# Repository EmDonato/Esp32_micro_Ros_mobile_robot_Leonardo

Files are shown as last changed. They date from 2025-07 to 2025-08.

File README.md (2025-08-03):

# Leonardo ESP32 Differential-Drive Unicycle Robot with micro-ROS and ROS 2 Humble

A mobile differential-drive unicycle robot powered by an **ESP32** microcontroller and seamlessly integrated with **ROS 2 Humble** and **micro-ROS** over Wi‑Fi. It fuses wheel encoder data and IMU measurements for accurate odometry, publishes LiDAR scans for SLAM, and subscribes to gamepad commands for teleoperation.

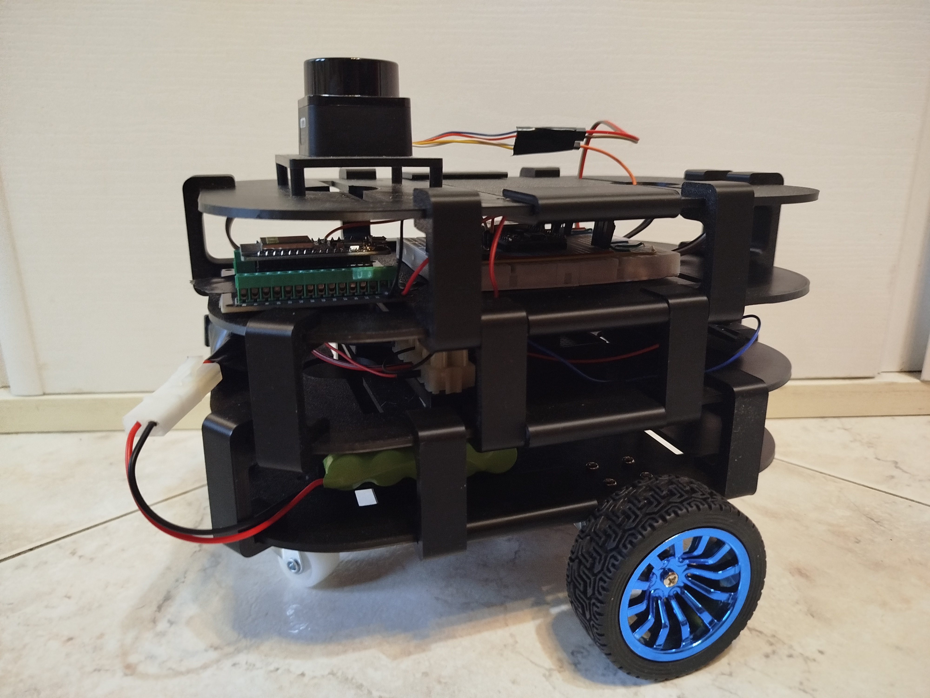
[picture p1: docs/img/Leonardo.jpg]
Leonardo Robot


> **Demo Video:** `docs/video/demo.mp4`

## 🗂️ Directory Layout

```text
/
├── leonardo/                 # Companion PC ROS 2 workspace
├── Leonardo_esp32/           # Primary ESP32 firmware
├── Leonardo_Lidar/           # Secondary ESP32 LiDAR node
├── libraries_arduinoIDE/     # Custom Arduino libraries
├── chassis_leonardo_3Dprint/ # 3D chassis CAD & STLs
├── docs/
│   ├── img/                  # Project images
│   └── video/                # Demo videos
└── README.md                 # This overview file
```

---

## 📦 Dependencies

Before getting started, make sure you have the following installed on your companion PC:

* **ROS 2 Humble Hawksbill**
* **micro-ROS Agent**

  ```bash
  sudo apt update
  sudo apt install ros-humble-micro-ros-agent
  ```
* **ROS Toolbox (slam\_toolbox)**

  ```bash
  sudo apt install ros-humble-slam-toolbox
  ```
* **Nav2 (Navigation2 stack)**

  ```bash
  sudo apt install ros-humble-nav2-bringup
  ```
* **RViz 2**

  ```bash
  sudo apt install ros-humble-rviz2
  ```

Additional system dependencies:

* Python 3.10+ packages: `colcon-common-extensions`, `rosdep`
* Arduino IDE (for firmware builds)

---

## 🔧 Hardware Setup

* **Microcontroller:** ESP32 DevKit (Wi‑Fi enabled)
* **Wheel Encoders:** Magnetic encoders on 12 V DC motors (25GA‑370, 130 RPM)
* **IMU:** MPU6050 via I2C (SDA/SCL)
* **Motor Driver:** L298N (PWM + digital direction pins)
  [motorDriver library](https://github.com/EmDonato/motorDriver.git)
* **LiDAR:** LD06 on secondary ESP32
  [LD06 module](https://github.com/EmDonato/ld06_esp32_microRos.git)
* **Battery:** 12 V NiMH pack
* **DC-DC Converter:** XL4015 step‑down module

---

## 🚀 Core Components

### Companion PC (`leonardo`)

* Teleoperation: `joy_node` & `teleop_twist_joy` for gamepad control
* Command Arbitration: `twist_mux` merging multiple `/cmd_vel` sources
* TF Broadcasters: `odom → base_link`, `base_link → base_laser`
* Time Synchronization: `/time_sync` messages align PC and ESP32 clocks
* SLAM Mapping: `slam_toolbox` for real-time 2D mapping
* Navigation: Nav2 bringup for path planning and recovery behaviors
* Visualization: preconfigured RViz2 layout

### ESP32 Firmware Modules

#### Main ESP32 (`Leonardo_esp32`)

* Odometry: complementary filter fusing encoder + IMU data
* Control: feedforward + PID loops generating motor commands
* micro-ROS: publishes `/odom`, subscribes `/cmd_vel_mux`, etc.

#### LiDAR Node (`Leonardo_Lidar`)

* Packet Parsing: decodes LD06 scan data into distances & confidences
* Scan Assembly: builds full 360° `LaserScan` messages
* Timestamp Sync: applies PC-derived offset for accurate stamps
* ROS 2 Interface: publishes scans and debug logs

### Libraries (`libraries_arduinoIDE`)

* Motor driver abstractions
* PID controller utilities (with feedforward and deadzone)

### Chassis Model (`chassis_leonardo_3Dprint`)

* CAD files and STL exports for 3D-printing the robot chassis

---

## 📋 Recent Updates

* **Unified Workspace:** merged PC and ESP32 projects into one directory structure
* **Time Sync:** added periodic `/time_sync` publisher and subscriber nodes
* **Twist\_mux:** configured priority and timeouts for manual vs. autonomous commands
* **IMU msg:** send imu msg
* **LiDAR Node:** enhanced error handling and synchronized scans every 30 s
* **Libraries:** released motor driver feedforward update and advanced PID tuning
* **Nav2 confi file** added config file for nav2 DWB control and PP control (not recommended)
---

## 🚀 Next Steps

* Integrate autonomous exploration

---

## ⚙️ Usage Examples

### 1️⃣ Source Workspace & Launch Leonardo

```bash
# Build and source your workspace:
colcon build --symlink-install
source install/setup.bash

# Launch the main robot bringup:
ros2 launch leonardo launch_leonardo.py
```

### 2️⃣ SLAM (slam\_toolbox)

```bash
ros2 launch slam_toolbox online_async_launch.py \
  slam_params_file:=/your/Full/path/Leonardo/src/mio_slam_toolbox/config/mapper_params_online_async.yaml
```

### 3️⃣ Navigation (Nav2)

```bash
ros2 launch nav2_bringup navigation_launch.py \
  params_file:=/your/Full/path/Leonardo/config/config_param_nav2DWB.yaml
```

---

## 📄 License

Released under the **MIT License**. See [LICENSE](LICENSE) for details.

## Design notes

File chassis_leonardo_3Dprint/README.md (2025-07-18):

# Chassis Components Directory

This directory contains all the 3D model files (`.stl` and `.f3d`) for the chassis components of the mobile robot platform. Use these files to assemble, simulate, or 3D-print the structural parts of the robot.

---

## Folder Structure

* **Screw\&Nut\_1/**

  * Contains M4 screws and nuts (package 1) used for fastening modular plates and support brackets.

* **Screw\&Nut\_2/**

  * Contains an additional set of M4 screws and nuts (package 2) for supplemental assembly needs.

* **basechassisLeonardo/**

  * Modular platform plates. Two of these plates combine to form the complete chassis base. Each plate shares the same hole pattern for M4 fasteners, ensuring interchangeable assembly.

* **reggiL298N/**

  * Support bracket designed to mount the L298N motor driver securely to the chassis.

* **wire\_linear\_bus/**

  * Cable guide structure for routing wiring along the linear bus of the chassis.

* **holder\_DCDC/**

  * Mounting bracket for the DC–DC converter module. Ensures stable positioning and clearance.

* **battery/**

  * Battery compartment housing. Designed to fit the standard Li‑ion battery pack, with snap‑fit features for quick insertion/removal.

* **jointer/**

  * Snap‑fit connector piece that links two modular base plates. Enables quick assembly without additional hardware.

* **jointer\_level/**

  * Strap‑like clamps that secure stacked base modules at different levels, allowing multi‑tiered chassis configurations.

---

## Usage Notes

* All assemblies use M4 hardware; verify screw lengths to avoid interference.
* `.f3d` files are native Fusion 360 designs—open them to inspect sketches, constraints, and assemblies.
* `.stl` exports are ready for slicing and 3D printing; check tolerances if fitting snap‑fits.
* Maintain consistent hole alignment when stacking modules with `jointer_level` clamps.

For questions or contributions, please open an issue in the repository.

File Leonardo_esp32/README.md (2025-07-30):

# Main ESP32 code
In this directory there is the core code for the project, the one to up load to the main esp32 of the robot.
It's organized in one .ino file and some .h and .cpp file so it's developed for arduinoIDE.
The purpose of the script is to build up all the microRos arquitecture for comunication and control.

## Software Architecture

### Leonardo.ino

* **setup()**: Initializes Serial, motor driver, IMU (with calibration), encoders (attach ISRs), PID controllers, and micro-ROS.
* **loop()**: Spins the micro-ROS executor to handle timers and subscriptions.

### Variable.hpp / Variable.cpp

* **Global Constants**: Hardware pin definitions, encoder PPR, wheel geometry, PID limits, etc.
* **Extern Objects**: `motorDriver`, `encoder_L`, `encoder_R`, `imu`, `odom_msg`, `executor`, etc.

### ISR.hpp / ISR\_Handlers

* **encoderISR\_L / encoderISR\_R**: Interrupt service routines for left/right encoders, updating tick counts and direction.

### EncoderPoseEstimator

* **Purpose**: Convert wheel RPM to linear and angular velocity and integrate heading.
* **Key Method**: `update(rpm_left, rpm_right, dt)` computes velocities and updates `theta_enc`.

### UnicycleOdometry

* **Purpose**: Integrate fused linear and angular velocities to track `(x, y, theta)` pose.
* **Key Method**: `updateFromFusion(v, omega, theta, dt)` updates position based on current heading.

### ControlTools

* **computeRPM**: Convert angular velocity (rad/s) to RPM.
* **normalize\_angle**: Wrap angles to `[-π, π]`.
* **complementaryFilter**: Fuse encoder and IMU yaw estimates.

### IMU\_Tools

* **calibrateGyroZ()**: Compute gyroscope Z-axis bias by sampling while stationary.

### micro\_ROS\_fun.hpp / micro\_ROS\_fun.cpp

* **initMicroROS()**: Configures Wi-Fi transport, ROS nodes, publishers, subscribers, timers, and executor.
* **Error Macros**: `RCCHECK`, `RCSOFTCHECK` for robust ROS calls.
* **Callbacks**:

  * `subscription_callback_control`: Updates wheel velocity references on command.
  * `timer_callback_IMU`: Integrates gyro data to update IMU yaw and send it in a dedicated topic.
  * `timer_callback_odometry`: Reads encoders, fuses yaw, updates odometry, and publishes.
  * `timer_callback_ctrl_PID`: Runs PID loops to drive motors.
  * `init_odom_msg`: Initializes odometry message fields.
  * `yaw_to_quat`: Utility to convert yaw to quaternion.
  * `get_now`: Retrieves current time for ROS stamps.
  * `get_n`: Retrieves current time for ROS stamps.

## Workflow

1. **Startup**: ESP32 boots, runs `setup()`, initializes all hardware and micro-ROS.
2. **Calibration**: Gyro bias is calculated by `calibrateGyroZ()`.
3. **Periodic Tasks**:
   * **IMU Timer**: Updates IMU-based yaw every 10 ms an sed it.
   * **Odometry Timer**: Every 50 ms, encoder RPMs are read, heading fused, and odometry published.
   * **Control Timer**: Every 50 ms, PID computes motor commands based on velocity references.
4. **Control**: Velocity commands published to `/velocity_ctrl` topic are received and processed.
5. **Execution**: `loop()` continuously spins the ROS executor to service callbacks.
## micro-ROS Agent & Arduino Library Setup

To enable communication between your ESP32 robot and the ROS 2 network, follow these steps (refer to the official guide: [https://github.com/micro-ROS/micro\_ros\_arduino](https://github.com/micro-ROS/micro_ros_arduino)):

1. **Install and Run the micro-ROS Agent**

   * Ensure ROS 2 Humble is installed on your host (PC or Raspberry Pi).
   * Build and run the agent for UDP transport:

     ```bash
     ros2 run micro_ros_agent micro_ros_agent udp4 --port 8888
     ```

2. **Configure the Arduino micro-ROS Library**

   * Update your workspace’s `colcon.meta` to increase RMW limits:

     ```json
     {
       "rmw_microxrcedds": {
         "cmake-args": [
           "-DRMW_UXRCE_MAX_NODES=5",
           "-DRMW_UXRCE_MAX_PUBLISHERS=10",
           "-DRMW_UXRCE_MAX_SUBSCRIPTIONS=5",
           "-DRMW_UXRCE_MAX_SERVICES=1",
           "-DRMW_UXRCE_MAX_CLIENTS=1",
           "-DRMW_UXRCE_MAX_HISTORY=4",
           "-DRMW_UXRCE_TRANSPORT=custom"
         ]
       }
     }
     ```
   * Rebuild the `rmw_microxrcedds` package:

     ```bash
     colcon build --merge-install --packages-select rmw_microxrcedds
     ```

3. **Verify Connectivity**

   * Be sure to change the wifi parameters with your own parameters (micro_ros_fun.cpp)

This configuration lets your ESP32 publish odometry and subscribe to velocity commands over ROS 2 using micro-ROS.

## Detailed ROS 2 Integration

### Message Types

* **nav\_msgs/Odometry**: publishes robot pose (position + orientation) and velocity.
* **geometry\_msgs/Vector3**: subscribes to control input (left and right wheel angular velocities).

### Published Topics

* **/odom** (`nav_msgs/Odometry`)

  * **Description**: Robot's pose and velocity relative to the `odom` frame.
  * **Message Fields**:

    * `header.stamp`: Timestamp of measurement (built from `millis()`).
    * `header.frame_id`: "odom".
    * `child_frame_id`: "base\_link".
    * `pose.pose.position`: X, Y coordinates.
    * `pose.pose.orientation`: Quaternion from fused yaw.
    * `twist.twist.linear.x`: Linear velocity.
    * `twist.twist.angular.z`: Angular velocity.

* **/debug_log** (`std_msgs/msg/string`)

* **Description**: Log message to advise about the currents status of the microRos inizialization.
  
* **/imu/data** (`sensor_msgs/msg/imu`)

  * **Description**: Robot's IMU data .
 **Message Fields**:

- `header` (`std_msgs/Header`)
  - `stamp` (`builtin_interfaces/Time`): Timestamp of the measurement
  - `frame_id` (`string`): Reference frame (e.g., `"base_link"` or `"imu_link"`)

- `orientation` (`geometry_msgs/Quaternion`)
  - `x`, `y`, `z`, `w`: Orientation as quaternion

- `orientation_covariance` (`float64[9]`): Row-major 3×3 covariance matrix of orientation

- `angular_velocity` (`geometry_msgs/Vector3`)
  - `x`, `y`, `z`: Angular velocity in rad/s

- `angular_velocity_covariance` (`float64[9]`): Row-major 3×3 covariance matrix of angular velocity

- `linear_acceleration` (`geometry_msgs/Vector3`)
  - `x`, `y`, `z`: Linear acceleration in m/s²

- `linear_acceleration_covariance` (`float64[9]`): Row-major 3×3 covariance matrix of linear acceleration
### Subscribed Topics

* **cmd_vel_mux** (`geometry_msgs/msg/twist`)

  * **Description**: Target angular velocities for left (x) and right (y) wheels.
  * **Usage**: Received values are stored in `w_L_ref` and `w_R_ref`, converted to RPM, and fed into PID controllers.

## PID Control library
findable here: https://github.com/EmDonato/PID_control.git or in the libraries_arduinoIDE (recommended)
* **Controllers**: Two independent PID loops for left and right wheels
* **Feedforward**: Enabled to improve dynamic response
* **Deadzone**: Zero threshold prevents jitter around zero velocity

## Calibration

* **Gyroscope**: `calibrateGyroZ()` averages 500 samples to compute bias

---
---

> Once these steps are complete, the robot will be able to receive correct velocity commands, navigate autonomously, and provide real-time diagnostic data for easier debugging and system validation.

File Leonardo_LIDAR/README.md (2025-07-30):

# LD06 LiDAR + ESP32 (Secondary Node) + micro-ROS Humble

This project enables the integration of the LD06 LiDAR sensor with an **ESP32** microcontroller as a **dedicated LiDAR node**, using the **micro-ROS Humble** stack to publish `sensor_msgs/msg/LaserScan` over ROS 2.

---

## 🛠️ Hardware Components

* **ESP32** 
* **LD06 LiDAR** (UART interface, 230400 baud)
* **micro-ROS Agent** running on a host computer or Raspberry Pi

---

## 📦 Software Components

* **Arduino framework for ESP32**
* **micro-ROS Arduino client** for ROS 2 Humble

---
## 🚀 Main Node Overview (`Leonardo_LIDAR.ino`)

This sketch implements:

1. **Wi-Fi transport** for micro-ROS over Ethernet/Wi-Fi.
2. **Publishers**:

   * `/scan` (`sensor_msgs/msg/LaserScan`): LiDAR data
   * `/lidar/debug_log` (`std_msgs/msg/String`): debug messages
3. **Subscriber**:

   * `/time_sync` (`builtin_interfaces/msg/Time`): external timestamp for time synchronization
4. **Executor** to handle time sync callback.
5. **Scan buffer management** and **synchronized publishing**.

### Key Functions

#### `resetLidarScanBuffer()`

Clears `ranges[]`, `intensities[]`, `lidar_angle_collected[]`, and resets `lidar_count_received`.

#### `isLidarScanComplete()`

Returns `true` when `lidar_count_received >= RESOLUTION` (360 points collected).

#### `lidar_get_sync_time()`

Computes ROS time by:

* Calling `rmw_uros_epoch_millis()` to get current microcontroller time (μs)
* Adding `lidar_time_offset_us` (computed from last `/time_sync` message)
* Returning adjusted `builtin_interfaces__msg__Time` (sec, nanosec)

#### `lidar_time_callback(const void * msgin)`

* Receives a `builtin_interfaces/msg/Time` from the PC
* Computes offset: `received_us - now_us`
* Sets `lidar_time_synced = true`
* Publishes a debug log on `/lidar/debug_log`

#### `lidar_publish_debug(const char * msg)`

Publishes a string message to the `/lidar/debug_log` topic.

---

## 🔄 `setup()` & `loop()` Flow

```cpp
void setup() {
  // Serial & Wi-Fi init
  Serial.begin(115200);
  set_microros_wifi_transports(...);

  // micro-ROS: support, node, publishers, subscriber, executor
  rclc_support_init(...);
  rclc_node_init_default(..., "lidar_node", ...);
  rclc_publisher_init_default(..., "scan");
  rclc_publisher_init_default(..., "lidar/debug_log");
  rclc_subscription_init_default(..., "time_sync");
  rclc_executor_init(...);
  rclc_executor_add_subscription(..., lidar_time_callback);

  // LaserScan msg initialization (frame_id, angle params, buffers)
  lidar_scan_msg.header.frame_id = "base_laser";
  lidar_scan_msg.angle_min = 0.0f;
  lidar_scan_msg.angle_max = 2.0f * M_PI;
  lidar_scan_msg.angle_increment = 2.0f * M_PI / RESOLUTION;
  lidar_scan_msg.scan_time = 1.0f / 10.0f;
  lidar_scan_msg.range_min = 0.02f;
  lidar_scan_msg.range_max = 12.0f;
  lidar_scan_msg.ranges.data = lidar_ranges;
  lidar_scan_msg.intensities.data = lidar_intensities;

  // LiDAR init & buffer reset
  lidar.Init(RX_PIN);
  resetLidarScanBuffer();
}

void loop() {
  // Handle incoming time_sync messages
  rclc_executor_spin_some(&lidar_executor, RCL_MS_TO_NS(1));

  // Wait until first time sync is received
  if (!lidar_time_synced) {
    Serial.println("[WARN] Waiting for lidar time sync...");
    return;
  }

  // Read and parse LiDAR data
  lidar.read_lidar_data();

  if (!lidar.angles.empty()) {
    // Accumulate scan points
    for (...) {
      // convert mm to m, validate range
      // store ranges[deg], intensities[deg]
    }

    // Publish when full 360° scan complete
    if (isLidarScanComplete()) {
      lidar_scan_msg.header.stamp = lidar_get_sync_time();
      rcl_publish(&lidar_scan_pub, &lidar_scan_msg, NULL);
      resetLidarScanBuffer();

      // Periodic debug every 30s
      if (!lidar_scan_published_once ||
          (rmw_uros_epoch_millis() / 1000) % 30 == 0) {
        lidar_publish_debug("[INFO] LiDAR scan published");
        lidar_scan_published_once = true;
      }
    }
  }
}
```

* **Time synchronization** ensures all scans carry a timestamp coherent with the companion PC.
* A new time sync is accepted whenever a `/time_sync` message arrives (recommended every 30 s).

---

## 📡 ROS 2 Topics

* **/scan** (`sensor_msgs/msg/LaserScan`) — LiDAR full 360° scan at \~10 Hz
* **/lidar/debug\_log** (`std_msgs/msg/String`) — Status and debug messages
* **/time\_sync** (`builtin_interfaces/msg/Time`) — External timestamp for time alignment

---

## ✅ Status

✅ Fully functional LiDAR node with time-synced publishing
🚧 Ensure companion PC publishes `/time_sync` at least every 30 s
📤 Ready for integration with mapping, SLAM, or obstacle avoidance stacks

---

## 🙏 Acknowledgements

Special thanks to [**Inoue Minoru (henjin0)**](https://github.com/henjin0/Lidar_LD06_for_Arduino) for the LD06 decoding library.

*This ESP32 node cleanly separates LiDAR data processing and synchronized ROS 2 publishing, facilitating modular integration into navigation systems.*

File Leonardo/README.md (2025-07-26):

# Mobile Robot ROS2 Teleoperation and SLAM

This repository contains the ROS2 components for controlling a differential‑drive mobile robot with micro-ROS integration https://github.com/EmDonato/Esp32_micro_Ros_mobile_robot_Leonardo.git. It provides teleoperation, static and dynamic TF broadcasters, odometry-to-TF conversion, and SLAM Toolbox mapping, together with launch files and configuration for Rviz2 visualization.

---

## Repository Structure

```

leonardo/
├── build/                   # CMake build artifacts (generated)
├── install/                 # Install space (generated)
├── log/                     # Colcon and ROS2 logs (generated)
├── src/                     # Source files and package structure
│   ├── leonardo/            # Teleoperation control node package
│   │   ├── CMakeLists.txt   # Build instructions
│   │   ├── package.xml      # Package metadata
│   │   ├── launch/          # Launch files
│   │   │   └── teleop.launch.py
│   │   ├── src/             # Implementation source files
│   │   │   └── control_teleop.cpp
│   │   └── include/         # Public headers
│   │       └── leonardo/
│   │           └── control_teleop.hpp
│   ├── odom_to_tf_cpp/      # Odometry to TF broadcaster package
│   │   ├── CMakeLists.txt
│   │   ├── package.xml
│   │   └── src/
│   │       └── odom_to_tf_node.cpp
│   ├── laser_tf_cpp/        # Static TF broadcaster package
│   │   ├── CMakeLists.txt
│   │   ├── package.xml
│   │   └── src/
│   │       └── static_tf_base_laser.cpp
│   └── mio_slam_toolbox/    # SLAM Toolbox config and integration
│       ├── CMakeLists.txt
│       ├── package.xml
│       └── config/
│           └── slam_toolbox_config.yaml

```

---

## Environment and Dependencies

* **ROS2 Distribution**:  Humble 
* **micro-ROS Agent**: Installed under `~/Desktop/agent`
* **External Packages**:

  * `joy` and `teleop_twist_joy`
  * `slam_toolbox`
  * `tf2_ros`, `geometry_msgs`, `nav_msgs`

Install system dependencies and ROS2 packages:

```bash
sudo apt update
sudo apt install ros-${ROS_DISTRO}-joy ros-${ROS_DISTRO}-teleop-twist-joy \
                 ros-${ROS_DISTRO}-slam-toolbox ros-${ROS_DISTRO}-tf2-ros
```

---

## Building the Workspace

```bash
# From workspace root:
source /opt/ros/${ROS_DISTRO}/setup.bash
colcon build
source install/setup.bash
```

---

## Launching the System

### Teleoperation and TF Broadcasters

```bash
ros2 launch leonardo launch_leonardo.py
```

This launch file will:

1. Start the **joy\_node** to read your game controller.
2. Start **teleop\_twist\_joy** to convert joystick axes into `/cmd_vel` Twist messages.
3. Launch your **control\_teleop** node to compute individual wheel speeds and publish on `/velocity_ctrl`.
4. Start **odom\_to\_tf\_node** to broadcast odometry as TF (`odom` → `base_link`).
5. Start **static\_tf\_base\_laser** to publish the fixed transform (`base_link` → `base_laser`).
6. Run the **micro-ROS agent** (UDP6 on port 8888) to bridge ROS2 and embedded devices.

### SLAM Toolbox Mapping

```bash
ros2 launch slam_toolbox online_async_launch.py   slam_params_file:=Leonardo/src/mio_slam_toolbox/config/mapper_params_online_async.yaml
```

* **mode**: `mapping` to build a 2D occupancy grid.
* **scan\_topic**: defaults to `/scan` for LiDAR input.
* **odom\_frame**, **map\_frame**, **base\_frame**: frame conventions.

Adjust `slam_toolbox_config.yaml` parameters for resolution, loop closure, and optimization.

### RViz2 Visualization

```bash
rviz2
```

Use an RViz2 config that displays:

* TF frames (`odom`, `base_link`, `base_laser`, `map`)
* Laser scans on `/scan`
* SLAM map (`/map` topic)
* Odometry path or footprint visualization

---

## Docker Container (Optional)

A pre-built Docker container is available if you prefer an isolated environment. You can find it at:

```
<INSERT-DOCKER-CONTAINER-URL-HERE>
```

To run:

```bash
docker pull your-docker-repo/mobile-ros2:latest
docker run --rm -it \
  --network host \
  -v $(pwd):/workspace \
  mobile-ros2:latest /bin/bash
```

---

## Support

For issues, contributions, or questions, please open an issue on the GitHub repository.

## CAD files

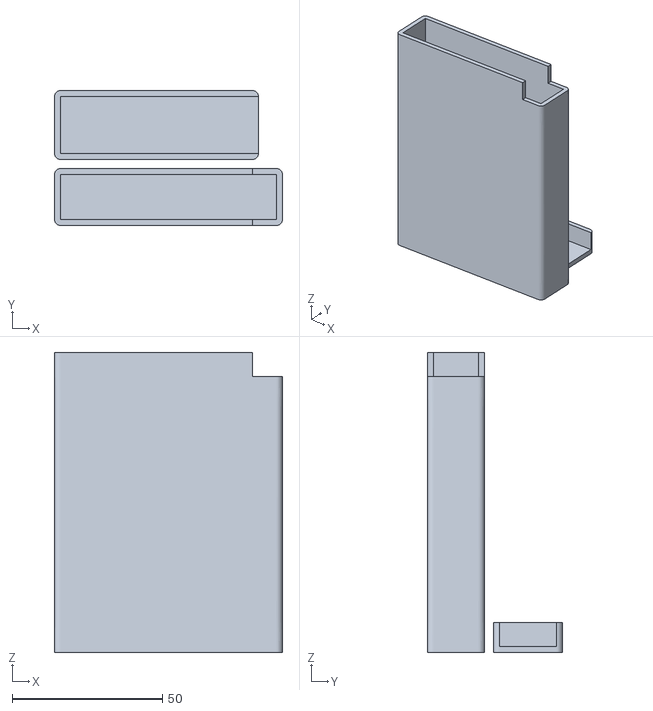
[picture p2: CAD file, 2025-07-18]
chassis_leonardo_3Dprint/battery.stl
76.0 x 45.0 x 100.0

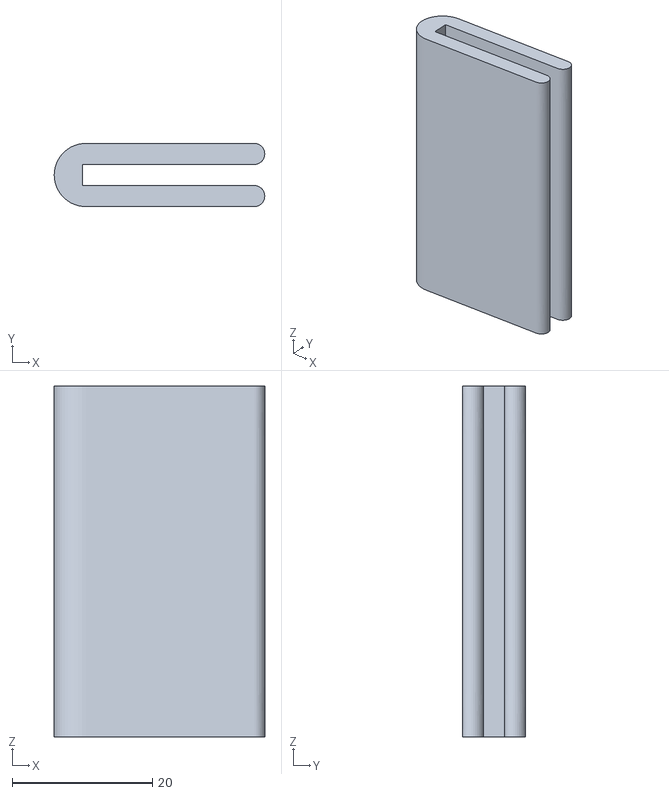
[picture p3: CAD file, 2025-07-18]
chassis_leonardo_3Dprint/jointer.stl
30.0 x 9.00 x 50.0

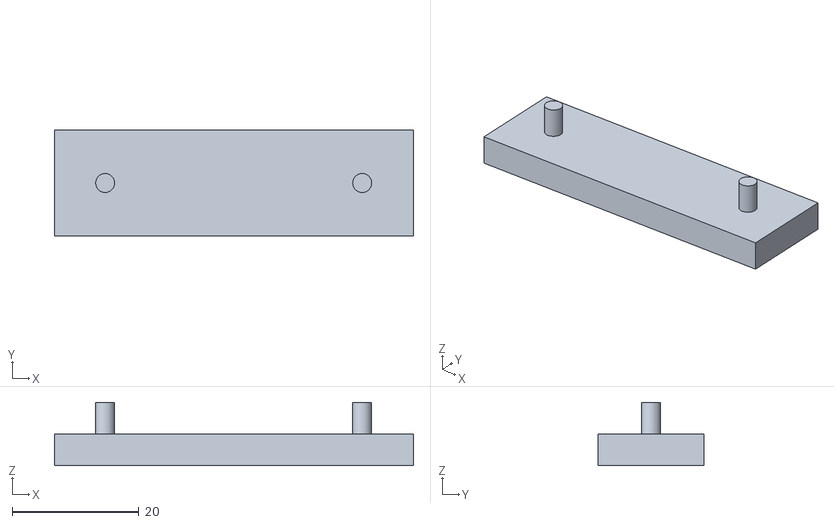
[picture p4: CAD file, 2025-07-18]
chassis_leonardo_3Dprint/wire_linear_bus.stl
56.7 x 16.7 x 10.0

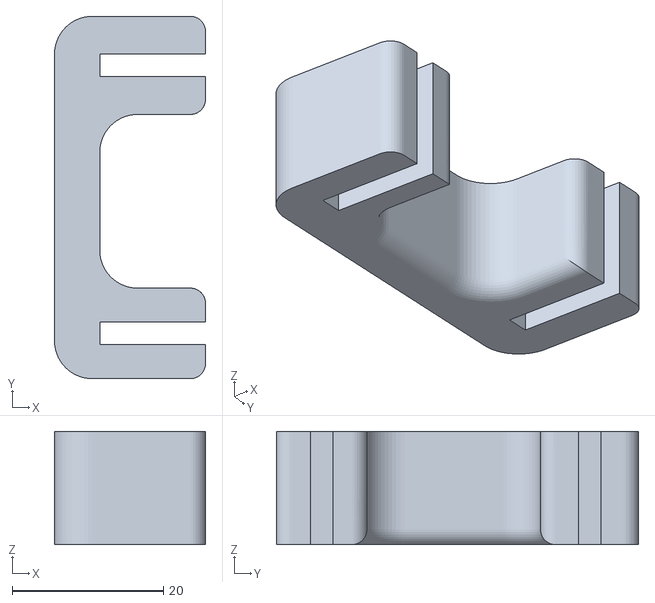
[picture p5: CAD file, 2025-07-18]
chassis_leonardo_3Dprint/jointer_level.stl
20.0 x 48.0 x 15.0

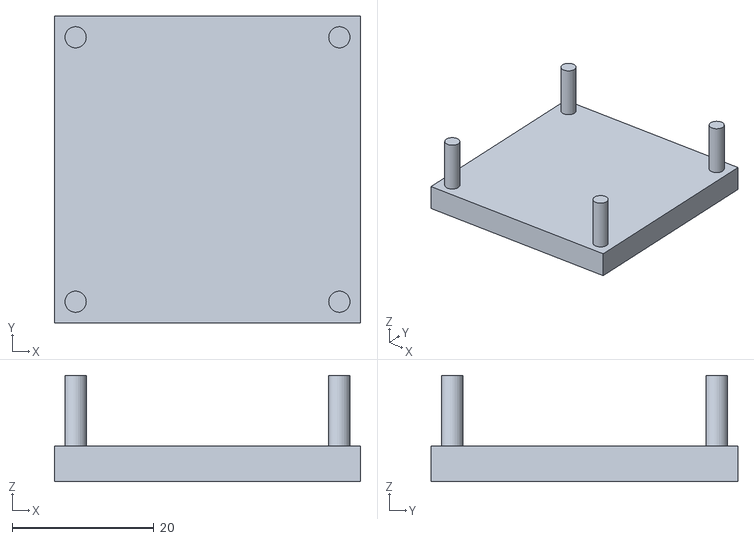
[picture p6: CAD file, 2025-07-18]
chassis_leonardo_3Dprint/reggiL298N.stl
43.2 x 43.3 x 15.0

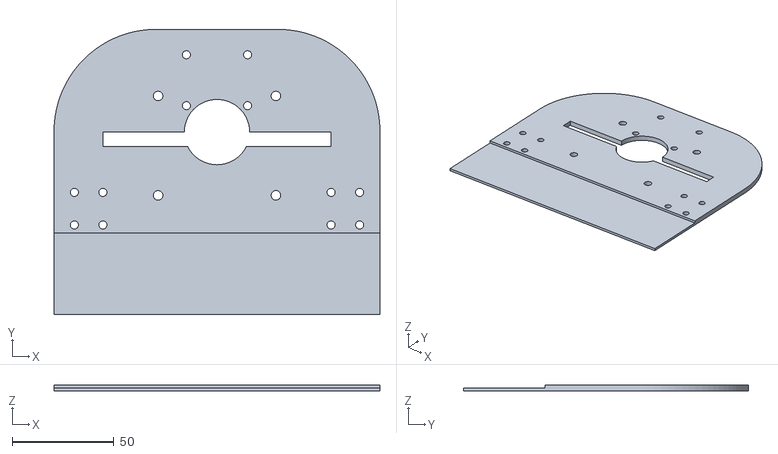
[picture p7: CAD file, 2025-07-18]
chassis_leonardo_3Dprint/baseChassisLeonardo.stl
160.0 x 140.0 x 3.00

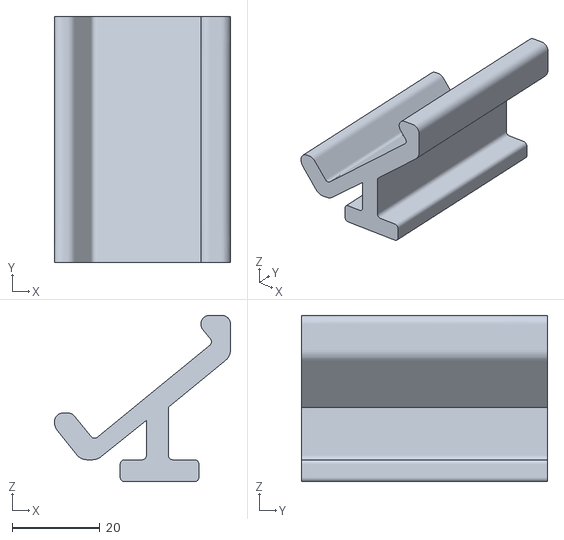
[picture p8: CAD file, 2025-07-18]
chassis_leonardo_3Dprint/holder_DCDC.stl
40.2 x 56.2 x 38.0

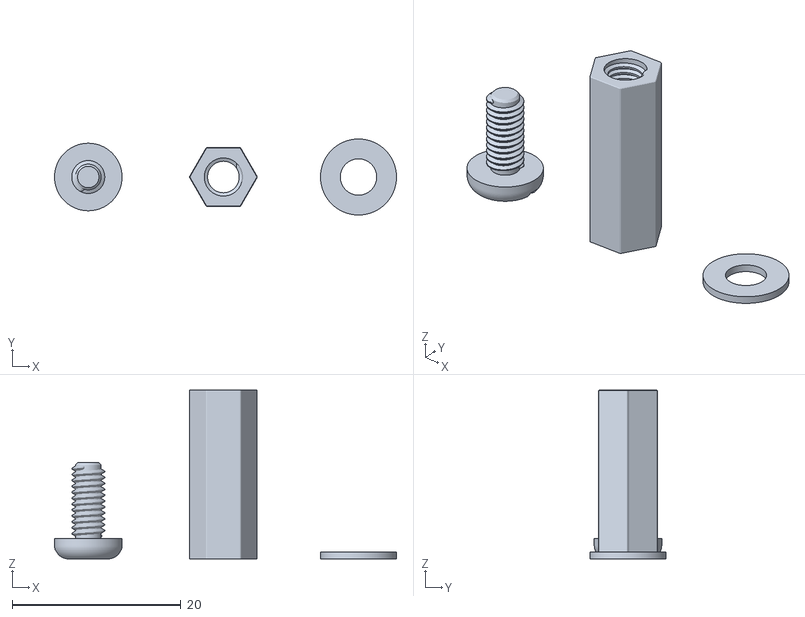
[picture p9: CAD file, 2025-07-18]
chassis_leonardo_3Dprint/Screw&Nut.stl
40.5 x 9.00 x 20.0

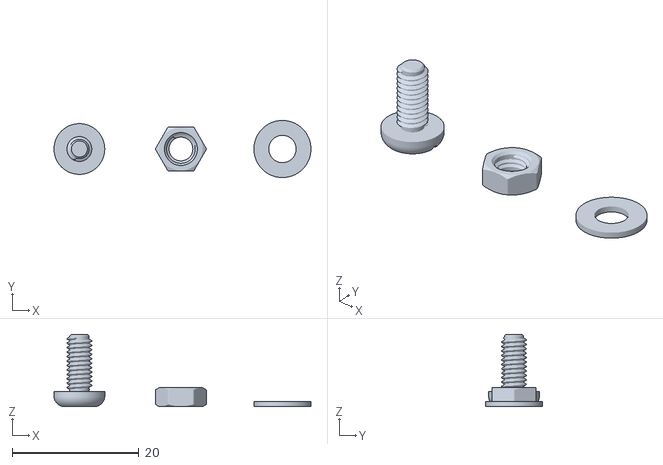
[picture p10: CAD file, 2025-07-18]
chassis_leonardo_3Dprint/Screw&Nut2.stl
40.5 x 9.00 x 11.4

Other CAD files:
chassis_leonardo_3Dprint/battery.f3d
chassis_leonardo_3Dprint/jointer.f3d
chassis_leonardo_3Dprint/reggiL298N.f3d
chassis_leonardo_3Dprint/sostegno_DCDC.f3d
chassis_leonardo_3Dprint/wire_linear_bus.f3d

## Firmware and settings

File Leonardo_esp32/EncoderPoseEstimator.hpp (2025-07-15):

#ifndef ENCODERPOSEESTIMATOR_H
#define ENCODERPOSEESTIMATOR_H

/**
 * @class EncoderPoseEstimator
 * @brief Estimates the robot's orientation and velocities using wheel encoder data.
 *
 * Provides methods to update yaw (theta), linear velocity, and angular velocity
 * based on wheel RPM readings.
 */
class EncoderPoseEstimator {
public:
    /**
     * @brief Constructor.
     * @param wheel_radius Radius of the wheels in meters.
     * @param wheel_separation Distance between the two wheels in meters.
     */
    EncoderPoseEstimator(float wheel_radius, float wheel_separation);

    /**
     * @brief Updates the pose estimate using wheel RPMs.
     * @param rpm_left  Left wheel speed in RPM (signed).
     * @param rpm_right Right wheel speed in RPM (signed).
     * @param dt         Time elapsed since the last update, in seconds.
     *
     * Converts RPM to linear wheel speeds, computes the average linear velocity
     * and differential angular velocity, then integrates to update the heading.
     */
    void update(float rpm_left, float rpm_right, float dt);

    /**
     * @brief Returns the current estimated yaw angle (theta).
     * @return Estimated yaw in radians within the range [-π, +π].
     */
    float getThetaEncoder() const;

    /**
     * @brief Returns the current estimated linear velocity of the robot.
     * @return Linear velocity in meters per second.
     */
    float getLinearVelocity() const;

    /**
     * @brief Returns the current estimated angular velocity of the robot.
     * @return Angular velocity in radians per second.
     */
    float getAngularVelocity() const;

    // TODO: Enable this if manual correction of the estimated heading is required.
    // void setCorrectedTheta(float corrected_theta);

private:
    float R_;         /**< Wheel radius [m] */
    float L_;         /**< Distance between wheels [m] */
    float theta_enc_; /**< Estimated yaw angle from encoders [rad] */
    float v_;         /**< Estimated linear velocity [m/s] */
    float omega_;     /**< Estimated angular velocity [rad/s] */
};

#endif // ENCODERPOSEESTIMATOR_H

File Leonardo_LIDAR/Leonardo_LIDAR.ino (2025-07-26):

#include <micro_ros_arduino.h>
#include <rcl/rcl.h>
#include <rclc/rclc.h>
#include <rclc/executor.h>
#include <sensor_msgs/msg/laser_scan.h>
#include <builtin_interfaces/msg/time.h>
#include <std_msgs/msg/string.h>
#include "LD06forArduino.h"

#define RESOLUTION 360
#define RX_PIN 16
#define TX_PIN 17
#define BAUDRATE 230400


// Wi-Fi config
char wifiNetName[]  = "FASTWEB-USA6DG";
char wifiPassword[] = "26KCXAYRSU";
char personalIP[]   = "192.168.1.56";

// micro-ROS entities
rclc_support_t lidar_support;
rcl_node_t lidar_node;
rcl_allocator_t lidar_allocator;
rcl_publisher_t lidar_scan_pub;
rcl_publisher_t lidar_debug_pub;
rcl_subscription_t lidar_time_sub;
rclc_executor_t lidar_executor;

// LaserScan and LD06
LD06forArduino lidar;
sensor_msgs__msg__LaserScan lidar_scan_msg;
std_msgs__msg__String lidar_debug_msg;
builtin_interfaces__msg__Time lidar_time_msg;

float lidar_ranges[RESOLUTION];
float lidar_intensities[RESOLUTION];
bool lidar_angle_collected[RESOLUTION];
int lidar_count_received = 0;

// Time sync
int64_t lidar_time_offset_us = 0;
bool lidar_time_synced = false;
bool lidar_scan_published_once = false;

/**
 * @brief Reset buffers for 360° scan
 */
void resetLidarScanBuffer() {
  for (int i = 0; i < RESOLUTION; ++i) {
    lidar_ranges[i] = NAN;
    lidar_intensities[i] = 0.0f;
    lidar_angle_collected[i] = false;
  }
  lidar_count_received = 0;
}

/**
 * @brief Check if full scan has been received
 */
bool isLidarScanComplete() {
  return lidar_count_received >= RESOLUTION;
}

/**
 * @brief Return time in ROS format adjusted with offset
 */
builtin_interfaces__msg__Time lidar_get_sync_time() {
  builtin_interfaces__msg__Time t;
  int64_t now_us = rmw_uros_epoch_millis() * 1000;
  int64_t synced_us = now_us + lidar_time_offset_us;
  t.sec = synced_us / 1000000;
  t.nanosec = (synced_us % 1000000) * 1000;
  return t;
}

/**
 * @brief Publish a debug message on /lidar/debug_log
 */
void lidar_publish_debug(const char * msg) {
  lidar_debug_msg.data.data = (char *)msg;
  lidar_debug_msg.data.size = strlen(msg);
  lidar_debug_msg.data.capacity = lidar_debug_msg.data.size + 1;
  rcl_publish(&lidar_debug_pub, &lidar_debug_msg, NULL);
}

/**
 * @brief Callback for receiving synchronized time from PC
 */
void lidar_time_callback(const void * msgin) {
  const builtin_interfaces__msg__Time * t_msg = (const builtin_interfaces__msg__Time *)msgin;
  int64_t received_sec = t_msg->sec;
  int64_t received_nsec = t_msg->nanosec;
  int64_t received_us = received_sec * 1000000LL + received_nsec / 1000LL;
  int64_t now_us = rmw_uros_epoch_millis() * 1000;
  lidar_time_offset_us = received_us - now_us;
  lidar_time_synced = true;

  lidar_publish_debug("[INFO] Lidar time sync received and offset updated");
}

/**
 * @brief micro-ROS + LD06 setup
 */
void setup() {
  Serial.begin(115200);
  delay(1000);
  Serial.println("LD06 + micro-ROS + time sync + debug");

  // micro-ROS transport over Wi-Fi
  set_microros_wifi_transports(wifiNetName, wifiPassword, personalIP, 8888);
  delay(2000);

  lidar_allocator = rcl_get_default_allocator();
  rclc_support_init(&lidar_support, 0, NULL, &lidar_allocator);
  rclc_node_init_default(&lidar_node, "lidar_node", "", &lidar_support);

  // Publisher: /lidar/scan
  rclc_publisher_init_default(
    &lidar_scan_pub,
    &lidar_node,
    ROSIDL_GET_MSG_TYPE_SUPPORT(sensor_msgs, msg, LaserScan),
    "scan"
  );

  // Publisher: /lidar/debug_log
  rclc_publisher_init_default(
    &lidar_debug_pub,
    &lidar_node,
    ROSIDL_GET_MSG_TYPE_SUPPORT(std_msgs, msg, String),
    "lidar/debug_log"
  );

  // Subscriber: /lidar/time_sync
  rclc_subscription_init_default(
    &lidar_time_sub,
    &lidar_node,
    ROSIDL_GET_MSG_TYPE_SUPPORT(builtin_interfaces, msg, Time),
    "time_sync"
  );

  // Executor for time callback
  rclc_executor_init(&lidar_executor, &lidar_support.context, 1, &lidar_allocator);
rclc_executor_add_subscription(&lidar_executor, &lidar_time_sub, &lidar_time_msg, &lidar_time_callback, ON_NEW_DATA);

  // Init LaserScan message
  lidar_scan_msg.header.frame_id.data = (char*)"base_laser";
  lidar_scan_msg.header.frame_id.size = strlen("base_laser");
  lidar_scan_msg.header.frame_id.capacity = lidar_scan_msg.header.frame_id.size + 1;
  lidar_scan_msg.angle_min       = 0.0f;
  lidar_scan_msg.angle_max       = 2.0f * M_PI;
  lidar_scan_msg.angle_increment = (2.0f * M_PI) / RESOLUTION;
  lidar_scan_msg.scan_time       = 1.0f / 10.0f;
  lidar_scan_msg.time_increment  = lidar_scan_msg.scan_time / RESOLUTION;
  lidar_scan_msg.range_min       = 0.02f;
  lidar_scan_msg.range_max       = 12.0f;
  lidar_scan_msg.ranges.data     = lidar_ranges;
  lidar_scan_msg.ranges.size     = RESOLUTION;
  lidar_scan_msg.ranges.capacity = RESOLUTION;
  lidar_scan_msg.intensities.data = lidar_intensities;
  lidar_scan_msg.intensities.size = RESOLUTION;
  lidar_scan_msg.intensities.capacity = RESOLUTION;

  // Init LiDAR
  lidar.Init(RX_PIN);
  resetLidarScanBuffer();
}

/**
 * @brief Main loop: wait for sync, acquire and publish scan
 */
void loop() {
  rclc_executor_spin_some(&lidar_executor, RCL_MS_TO_NS(1));
  // Wait for time sync
  if (!lidar_time_synced) {
    Serial.println("[WARN] Waiting for lidar time sync...");
    return;
  }

  lidar.read_lidar_data();

  if (!lidar.angles.empty()) {
    for (size_t i = 0; i < lidar.angles.size(); ++i) {
      int deg = ((int)round(lidar.angles[i])) % 360;
      if (!lidar_angle_collected[deg]) {
        float dist_m = lidar.distances[i] / 1000.0f;

        if (dist_m < lidar_scan_msg.range_min || dist_m > lidar_scan_msg.range_max)
          lidar_ranges[deg] = std::numeric_limits<float>::infinity();
        else
          lidar_ranges[deg] = dist_m;

        lidar_intensities[deg] = lidar.confidences[i];
        lidar_angle_collected[deg] = true;
        lidar_count_received++;
      }
    }

    if (isLidarScanComplete()) {
      lidar_scan_msg.header.stamp = lidar_get_sync_time();
      rcl_publish(&lidar_scan_pub, &lidar_scan_msg, NULL);

      if (!lidar_scan_published_once) {
        lidar_publish_debug("[INFO] First LaserScan published after sync");
        lidar_scan_published_once = true;
      }

      resetLidarScanBuffer();
    }
  }
}

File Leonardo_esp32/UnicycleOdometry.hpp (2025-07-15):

#ifndef UNICYCLE_ODOMETRY_HPP
#define UNICYCLE_ODOMETRY_HPP

#include <stdint.h>

/**
 * @file UnicycleOdometry.hpp
 * @brief Declaration of the UnicycleOdometry class for tracking robot pose.
 *
 * This class maintains the robot's x, y position and orientation (theta)
 * by integrating linear and angular velocity inputs over time.
 */

/**
 * @typedef float64_t
 * @brief Alias for double precision floating point.
 */
typedef double float64_t;

/**
 * @class UnicycleOdometry
 * @brief Computes and stores odometry for a differential-drive robot.
 *
 * Uses fused velocity (v), angular rate (omega), and heading (theta) inputs
 * to update Cartesian pose coordinates and provides accessors for state.
 */
class UnicycleOdometry {
public:
    /**
     * @brief Constructor.
     * @param wheel_radius Radius of the robot wheels in meters.
     * @param wheel_separation Distance between the two wheels in meters.
     *
     * Initializes the pose (x, y, theta) and motion state (v, omega) to zero.
     */
    UnicycleOdometry(float wheel_radius, float wheel_separation);

    /**
     * @brief Updates odometry from fused motion data.
     * @param v     Linear velocity input in meters per second (m/s).
     * @param omega Angular velocity input in radians per second (rad/s).
     * @param theta Absolute orientation of the robot in radians (rad).
     * @param dt    Time delta since last update in seconds (s).
     *
     * Sets internal velocity and heading, then integrates to update x and y.
     */
    void updateFromFusion(float v, float omega, float theta, float dt);

    /**
     * @brief Gets the current X position.
     * @return X coordinate in meters.
     */
    float getX() const;

    /**
     * @brief Gets the current Y position.
     * @return Y coordinate in meters.
     */
    float getY() const;

    /**
     * @brief Gets the current orientation angle (theta).
     * @return Orientation in radians (rad).
     */
    float getTheta() const;

    /**
     * @brief Sets the current orientation angle.
     * @param theta New orientation in radians (rad).
     */
    void setTheta(float theta);

    /**
     * @brief Gets the last stored linear velocity.
     * @return Linear velocity in meters per second (m/s).
     */
    float getLinearVelocity() const;

    /**
     * @brief Gets the last stored angular velocity.
     * @return Angular velocity in radians per second (rad/s).
     */
    float getAngularVelocity() const;

private:
    float x_;       /**< Position X coordinate [m] */
    float y_;       /**< Position Y coordinate [m] */
    float theta_;   /**< Orientation angle (yaw) [rad] */
    float R_;       /**< Wheel radius [m] */
    float L_;       /**< Distance between wheels [m] */
    float v_;       /**< Linear velocity [m/s] */
    float omega_;   /**< Angular velocity [rad/s] */
};

#endif // UNICYCLE_ODOMETRY_HPP

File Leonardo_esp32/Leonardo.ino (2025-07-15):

#include <Arduino.h>
#include <Wire.h>
#include <Adafruit_GFX.h>
#include <Adafruit_SSD1306.h>
#include "Variable.hpp"
#include "ISR.hpp"
#include "micro_ROS_fun.hpp"
#include "IMU_tools.h"

/**
 * @file main.cpp
 * @brief Main entry point: initializes hardware, IMU, encoders, PID, and micro-ROS, then spins executor.
 */

/**
 * @brief Arduino setup function.
 *
 * - Initializes Serial port for debugging
 * - Configures and stops motor driver
 * - Initializes IMU over I2C, checks connection, and calibrates gyro
 * - Attaches encoder ISRs
 * - Configures PID controllers (reset, deadzone, feedforward)
 * - Initializes and starts micro-ROS support
 */
void setup() {
    // Serial debug interface
    Serial.begin(115200);

    // Motor driver initialization and stop
    motorDriver.init(pwmPinA, inPinA, inPinB, inPinC, inPinD, pwmPinB);
    motorDriver.stop();

    // IMU initialization over I2C
    Wire.begin(SDA_PIN, SCL_PIN);
    imu.initialize();
    if (!imu.testConnection()) {
        Serial.println("ERROR: IMU not detected!");
        while (true) {
            ; // Halt on IMU failure
        }
    }
    calibrateGyroZ();
    Serial.println("IMU ready.");

    // Attach encoder interrupt service routines
    encoder_L.begin(encoderISR_L);
    encoder_R.begin(encoderISR_R);

    // Configure PID controllers
    pid_R.reset();
    pid_R.setDeadZone(0);
    pid_L.reset();
    pid_L.setDeadZone(0);
    pid_R.setFeedforwardParams(20.88f, 500.85f);
    pid_L.setFeedforwardParams(20.88f, 500.85f);
    pid_L.enableFeedforward(1);
    pid_R.enableFeedforward(1);

    // Initialize odometry message headers
    nav_msgs__msg__Odometry__init(&odom_msg);
    rosidl_runtime_c__String__assign(&odom_msg.header.frame_id, "odom");
    rosidl_runtime_c__String__assign(&odom_msg.child_frame_id, "base_link");

    // Start micro-ROS and report status
    init_uRos_code = initMicroROS();
    Serial.print("micro-ROS init returned: ");
    Serial.println(init_uRos_code);
}

/**
 * @brief Arduino loop function.
 *
 * Spins the micro-ROS executor to handle callbacks and timers.
 */
void loop() {
    // Process pending ROS tasks (max 10 ms)
    rclc_executor_spin_some(&executor, RCL_MS_TO_NS(10));
}

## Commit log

2025-07-18 Add files via upload
    3D-print_chassis
    [Screw&Nut.stl, Screw&Nut2.stl, baseChassisRaffaello.stl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]
2025-07-24 Release 1.1: - Add IMU node and publisher - Add debug node and publisher - change message tipe of control topic from Vector3 to geometry_msgs/Twist
2025-07-25 Release 1.2: add 2 libraries: -PID -MotorDriver
2025-07-26 Update esp32 code for Lidar, add a video, Update companion PC code
2025-07-26 Removed submodule and added MotorDriver as normal directory
2025-07-26 Removed submodule and added Leonardo ROS2 nodes as regular directory
    [unicycle.urdf]
2025-07-30 HOTFIX negative velocity
